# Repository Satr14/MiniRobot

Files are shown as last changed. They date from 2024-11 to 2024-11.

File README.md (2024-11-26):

Tugas Pemrogaman Sistem Mekatronik

-> MINI ROBOT <-

-> Arduino Nano Wall Follower <-

Not Use : RST,D8,D9,REF

Button
	RST : reset

Switch Komunikasi Antar Arduino
	1: RX -> TX
	2: TX -> RX

Modul wifi ESP diganti dengan modul Bluetooth
	D10 (RX/PWM) : RX
	D11 (TX/Mosi1) : TX
	3V3	: Vcc dan Ch_Pd/En
	GND	: GND dan GPIO 0
	Not Use : (reset),(GPIO 2)

IMU 6050
	3V3 : pin 1 (3v3)
	A4 : pin 4 (SDA)
	A5 : pin 3 (SCL)
	no use : sisanya 
Yang digunakan untuk heading hanya sumbu z saja

Ultrasonic Kanan 
	Trig : D7
	Echo : D6
	
Ultrasonic Kiri
	Trig : D3
	Echo : D2

Ultrasonic Depan
	Trig : D5
	Echo : D4

-> Arduino Nano Line Follower <-

Not Use : RST,REF,A7

LCD I2C
	Address: 0X27
	A4 : SDA
	A5 : SCL

Driver Motor (HW-166)
	PWMA : D3
	AIN2 : D2
	AIN1 : D4
	STBY : D9
	BIN1 : D7
	BIN2 : D8
	PWMB : D5

Buzzer 
	Transistor : D6

Button
	RST : reset
	D12(1) : D12
	D11(2) : D11
	D13(3) : D13

Led
	- : D10

Led & Infrared
	infrared 1 : A0
	infrared 2 : A1
	infrared 3 : A2
	infrared 4 : A3
	infrared 5 : A6
	
Pembacaan Putih <720
Pembacaan Hitam >880

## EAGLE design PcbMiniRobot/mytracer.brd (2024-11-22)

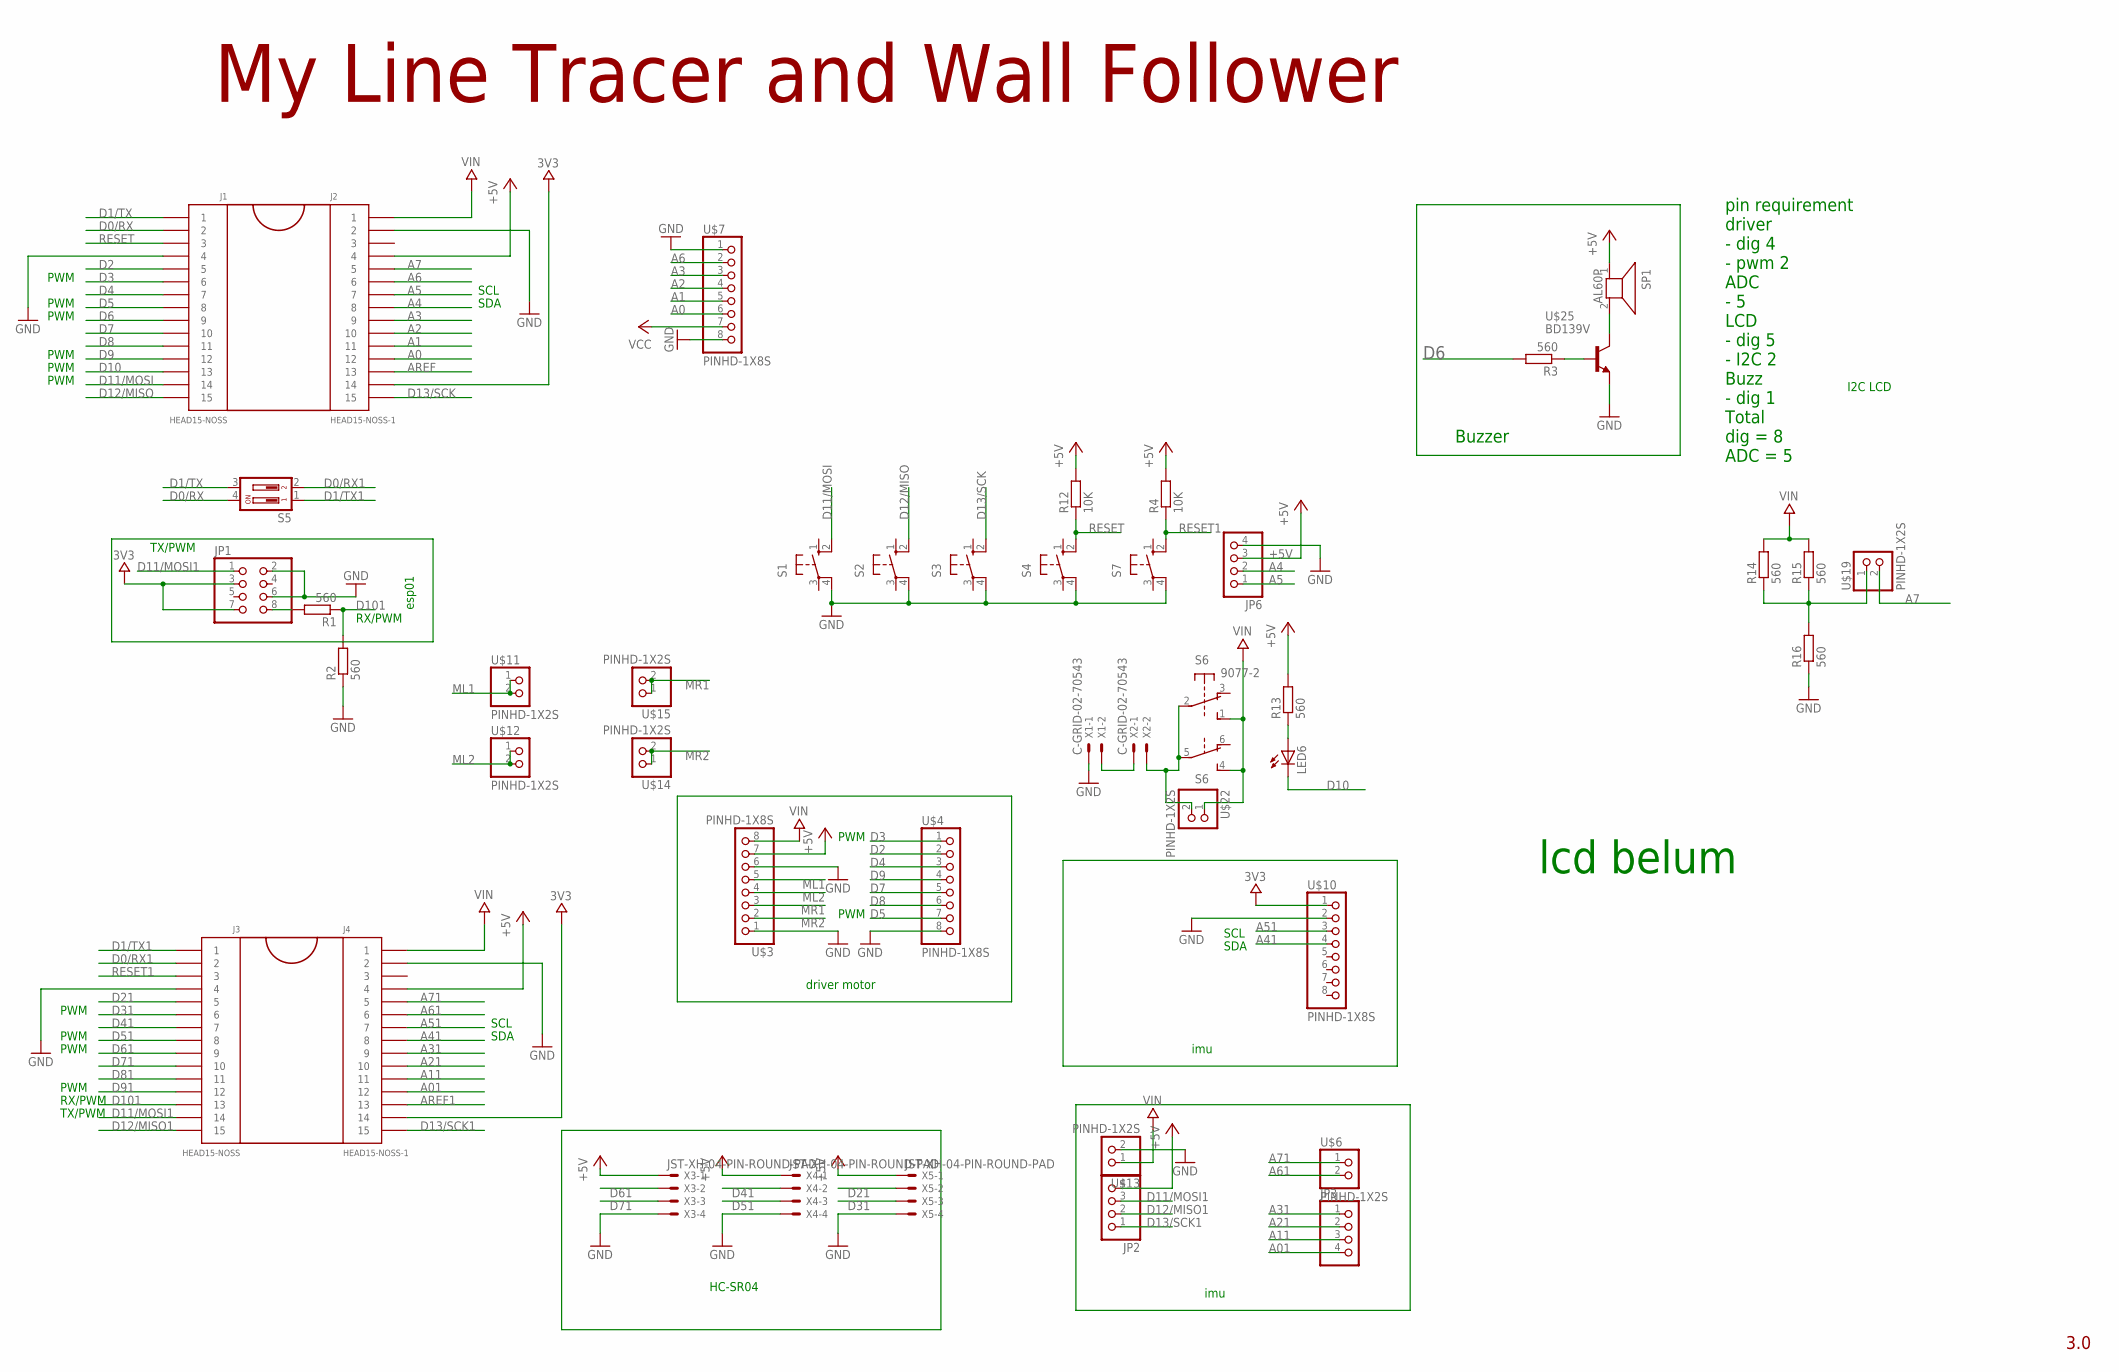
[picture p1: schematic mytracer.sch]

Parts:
J1, J3: HEAD15-NOSS
J2, J4: HEAD15-NOSS-1
JP1: PINHD-2X4; 2X04
JP2, JP3, JP6: PINHD-1X4; 1X04
LED6: LED3MM
R1, R2, R3, R13, R14, R15, R16: 560; M1206
R4, R12: 10K; M1206
S1, S2, S3, S4, S7: 10-XX; B3F-10XX
S5: DIP02YL
S6: 9077-2
SP1: AL60P
U$3, U$4, U$7, U$10: PINHD-1X8S; 1X08S
U$6, U$11, U$12, U$13, U$14, U$15, U$19, U$22: PINHD-1X2S; 1X02S
U$25: BD139V; TO126V
X1, X2: C-GRID-02-70543; 70543-02
X3, X4, X5: JST-XH-04-PIN-ROUND-PAD; JST-XH-04-PACKAGE-ROUND-PAD

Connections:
3V3: J2.14, J4.14, JP1.3, JP1.7, U$10.1
+5V: J2.4, J4.4, JP2.4, JP6.3, R4.2, R12.2, R13.2, SP1.1, U$3.7, X3.1, X4.1, X5.1
A0: J2.12, U$7.6
A1: J2.11, U$7.5
A01: J4.12, JP3.4
A2: J2.10, U$7.4
A3: J2.9, U$7.3
A4: J2.8, JP6.2
A5: J2.7, JP6.1
A6: J2.6, U$7.2
A7: J2.5, U$19.2
A11: J4.11, JP3.3
A21: J4.10, JP3.2
A31: J4.9, JP3.1
A41: J4.8, U$10.4
A51: J4.7, U$10.3
A61: J4.6, U$6.2
A71: J4.5, U$6.1
AREF: J2.13
AREF1: J4.13
D0/RX: J1.2, S5.4
D0/RX1: J3.2, S5.2
D1/TX: J1.1, S5.3
D1/TX1: J3.1, S5.1
D2: J1.5, U$4.2
D3: J1.6, U$4.1
D4: J1.7, U$4.3
D5: J1.8, U$4.7
D6: J1.9, R3.2
D7: J1.10, U$4.5
D8: J1.11, U$4.6
D9: J1.12, U$4.4
D10: J1.13, LED6.K (C)
D11/MOSI: J1.14, S1.2 (S1)
D11/MOSI1: J3.14, JP1.1, JP2.3
D12/MISO: J1.15, S2.2 (S1)
D12/MISO1: J3.15, JP2.2
D13/SCK: J2.15, S3.2 (S1)
D13/SCK1: J4.15, JP2.1
D21: J3.5, X5.2
D31: J3.6, X5.3
D41: J3.7, X4.2
D51: J3.8, X4.3
D61: J3.9, X3.2
D71: J3.10, X3.3
D81: J3.11
D91: J3.12
D101: J3.13, R1.1, R2.2
GND: J1.4, J2.2, J3.4, J4.2, JP1.2, JP1.6, JP6.4, R2.1, R16.1, S1.4 (P1), S2.4 (P1), S3.4 (P1), S4.4 (P1), S7.4 (P1), U$3.1, U$3.6, U$4.8, U$7.1, U$7.8, U$10.2, U$13.2, U$25.1 (E), X1.1, X3.4, X4.4, X5.4
ML1: U$3.5, U$11.1, U$11.2
ML2: U$3.4, U$12.1, U$12.2
MR1: U$3.3, U$15.1, U$15.2
MR2: U$3.2, U$14.1, U$14.2
unnamed: R14.1, R15.1, R16.2, U$19.1
unnamed: JP1.8, R1.2
unnamed: X1.2, X2.1
unnamed: S6.2, S6.5, U$22.2, X2.2
unnamed: LED6.A, R13.1
unnamed: R3.1, U$25.3 (B)
unnamed: SP1.2, U$25.2 (C)
RESET: J1.3, R12.1, S4.2 (S1)
RESET1: J3.3, R4.1, S7.2 (S1)
VCC: U$7.7
VIN: J2.1, J4.1, R14.2, R15.2, S6.1 (S), S6.4 (S), U$3.8, U$13.1, U$22.1

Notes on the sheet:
My Line Tracer and Wall Follower
3.0
Buzzer
pin requirement driver - dig 4 - pwm 2 ADC - 5 LCD - dig 5 - I2C 2 Buzz - dig 1 Total dig = 8 ADC = 5
SDA
SCL
PWM
I2C LCD
esp01
RX/PWM
TX/PWM
driver motor
imu
HC-SR04
lcd belum

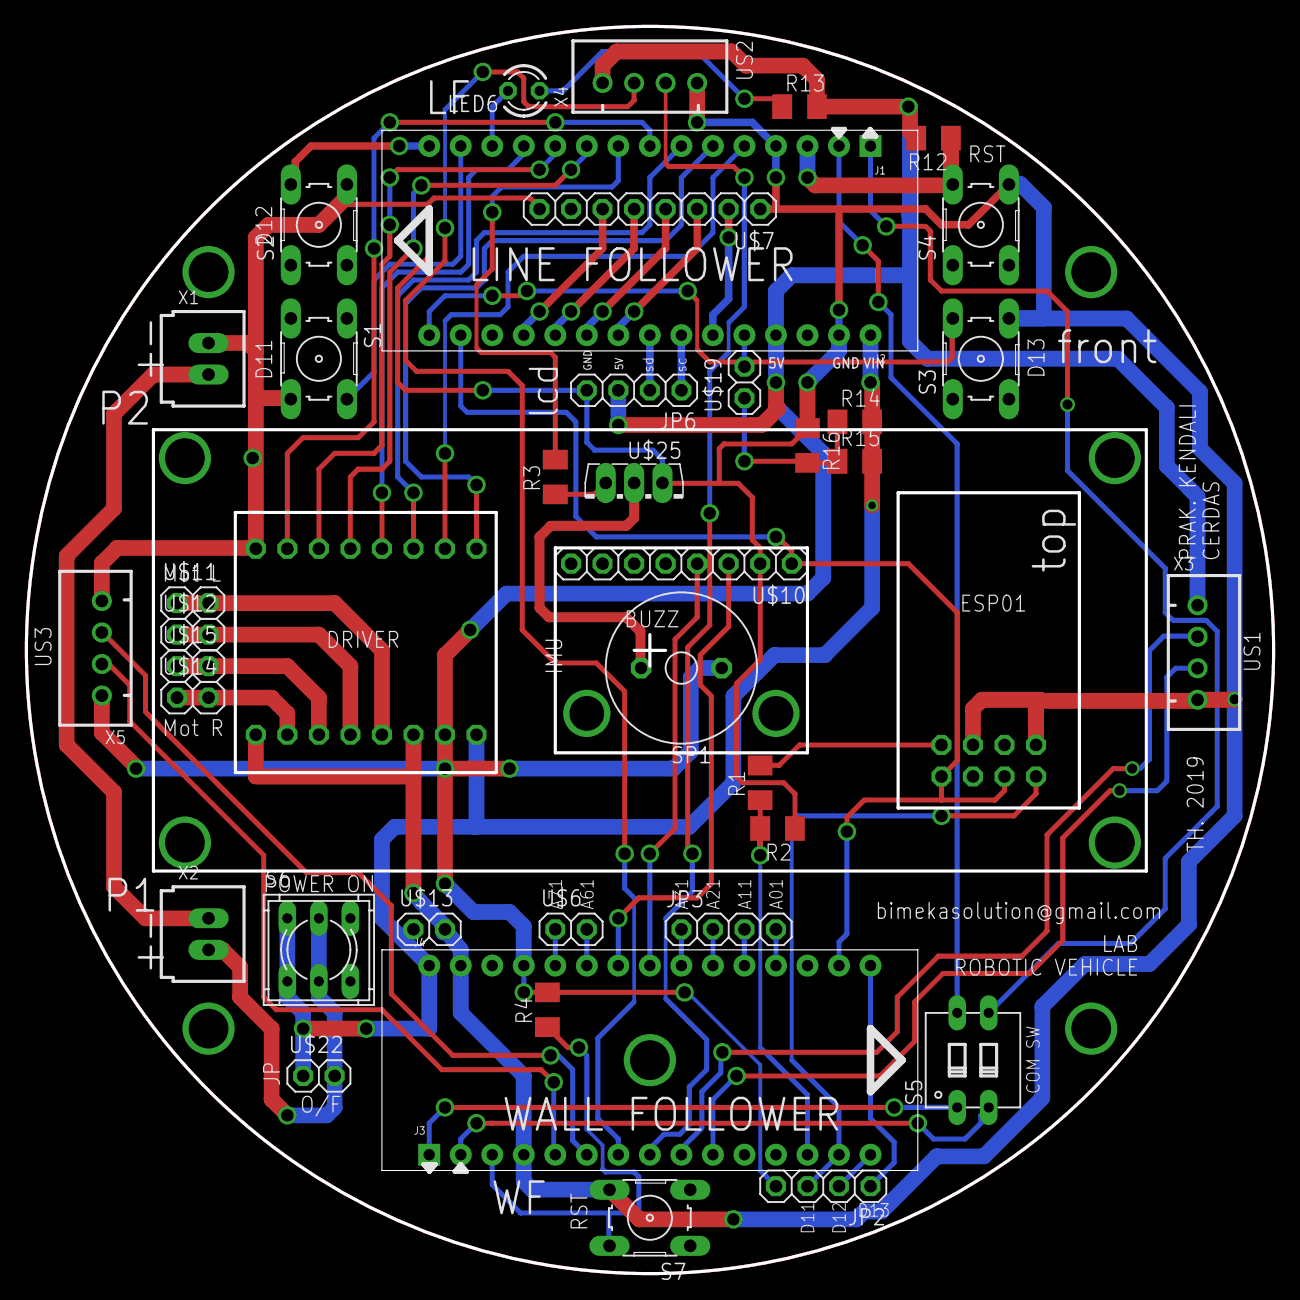
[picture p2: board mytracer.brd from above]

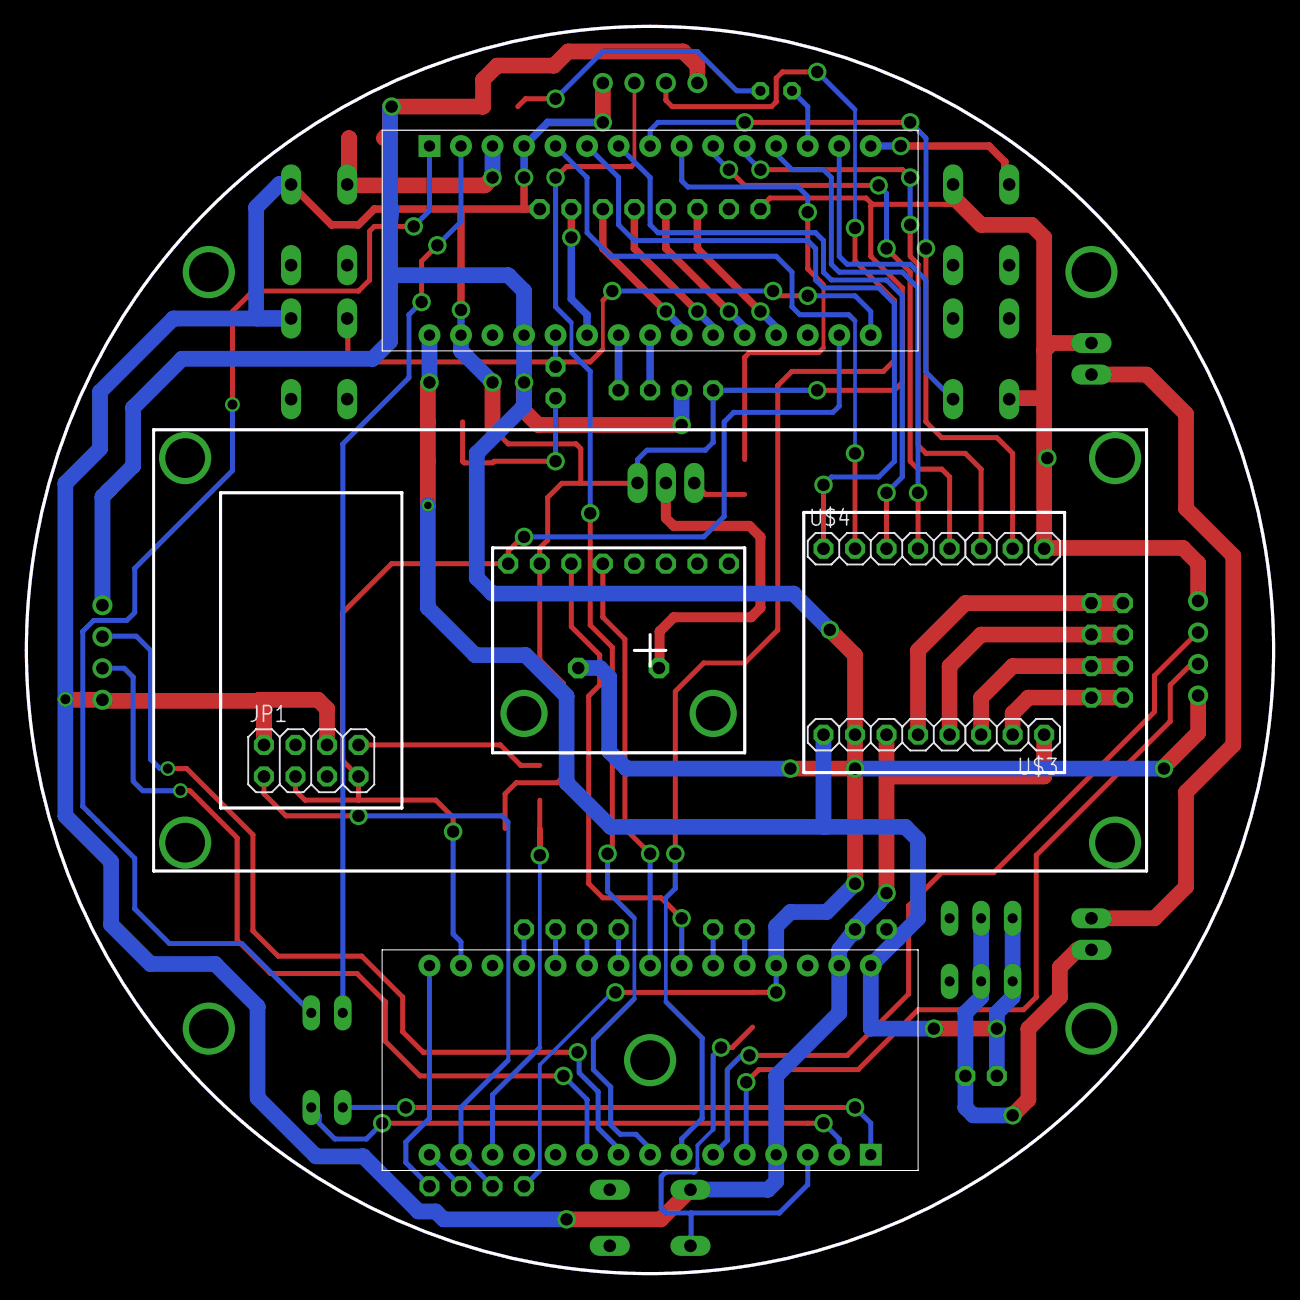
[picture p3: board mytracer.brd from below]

Board: 2 copper layers, 100.5 x 100.5 mm, 44 parts (3 on the bottom side), 59 nets.

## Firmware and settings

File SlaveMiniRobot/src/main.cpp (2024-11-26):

#include <Arduino.h>
#include <Wire.h>
#include <LiquidCrystal_I2C.h>

// Define pin motor
#define PWM1 3   // Motor A PWM
#define AIN1 2   // Motor A IN1
#define AIN2 4   // Motor A IN2
#define STBY 9   // Standby pin
#define PWM2 5   // Motor B PWM
#define BIN1 7   // Motor B IN1
#define BIN2 8   // Motor B IN2

// Define pin infrared sensors
const int IFR1 = A0;
const int IFR2 = A1;
const int IFR3 = A2;
const int IFR4 = A3;
const int IFR5 = A6;

const int led = 10;  // Pin LED for indication (optional)

// Buffer size for moving average
const int bufferSize = 10;

// Buffers for each sensor to store recent readings
int bufferIFR1[bufferSize] = {0};
int bufferIFR2[bufferSize] = {0};
int bufferIFR3[bufferSize] = {0};
int bufferIFR4[bufferSize] = {0};
int bufferIFR5[bufferSize] = {0};

// Index to keep track of the current position in the buffer
int bufferIndex = 0;

// Function to compute the moving average for a sensor
int movingAverage(int buffer[], int newValue) {
  buffer[bufferIndex] = newValue;  // Update the buffer with the new value
  int sum = 0;
  
  // Calculate the sum of all values in the buffer
  for (int i = 0; i < bufferSize; i++) {
    sum += buffer[i];
  }
  
  return sum / bufferSize;  // Return the average
}

// Set up motor
void setupMotors() {
  pinMode(PWM1, OUTPUT);  // Motor A PWM
  pinMode(AIN1, OUTPUT);  // Motor A IN1
  pinMode(AIN2, OUTPUT);  // Motor A IN2
  pinMode(STBY, OUTPUT);  // Standby pin
  pinMode(PWM2, OUTPUT);  // Motor B PWM
  pinMode(BIN1, OUTPUT);  // Motor B IN1
  pinMode(BIN2, OUTPUT);  // Motor B IN2
  
  digitalWrite(STBY, HIGH); // Ensure motors are not in standby
}

void motorB_CW(int speed) {
  digitalWrite(AIN1, HIGH); // AIN1 HIGH
  digitalWrite(AIN2, LOW);  // AIN2 LOW
  analogWrite(PWM1, speed); // Set motor speed using PWM
}

void motorB_CCW(int speed) { // Maju
  digitalWrite(AIN1, LOW);  // AIN1 LOW
  digitalWrite(AIN2, HIGH); // AIN2 HIGH
  analogWrite(PWM1, speed); // Set motor speed using PWM
}

void motorA_CW(int speed) {
  digitalWrite(BIN1, HIGH); // BIN1 HIGH
  digitalWrite(BIN2, LOW);  // BIN2 LOW
  analogWrite(PWM2, speed); // Set motor speed using PWM
}

void motorA_CCW(int speed) { // Maju
  digitalWrite(BIN1, LOW);  // BIN1 LOW
  digitalWrite(BIN2, HIGH); // BIN2 HIGH
  analogWrite(PWM2, speed); // Set motor speed using PWM
}

char Incoming_value = 0;
bool lineTracerMode = false;

LiquidCrystal_I2C lcd(0x27, 16, 2); // Set the LCD address to 0x27 for a 16 chars and 2 line display

void setup() {
  setupMotors();
  Serial.begin(9600);
  lcd.init(); // Initialize the LCD
  lcd.backlight();
  lcd.setCursor(3, 0);
  lcd.print("Mini Robot");
  lcd.setCursor(2, 1);
  lcd.print("Mode: Manual");

  // Initialize infrared sensors and LED
  pinMode(IFR1, INPUT);
  pinMode(IFR2, INPUT);
  pinMode(IFR3, INPUT);
  pinMode(IFR4, INPUT);
  pinMode(IFR5, INPUT);
  pinMode(led, OUTPUT);
}

int lastDirection = 0;  // 0: tidak ada arah, 1: kiri, 2: kanan
unsigned long lastLineDetectionTime = 0;
const unsigned long MAX_NO_LINE_DURATION = 1000; // 1 detik tanpa garis

// Fungsi untuk mencari garis
void searchForLine(int lastKnownDirection) {
  // Strategi pencarian garis
  switch(lastKnownDirection) {
    case 1:  // Terakhir belok kiri
      // Putar mencari garis ke kiri
      motorA_CCW(50);
      motorB_CW(50);
      digitalWrite(led, LOW);
      break;
    
    case 2:  // Terakhir belok kanan
      // Putar mencari garis ke kanan
      motorA_CW(50);
      motorB_CCW(50);
      digitalWrite(led, LOW);
      break;
    
    default:  // Jika tidak ada arah yang diketahui
      // Putar di tempat secara bergantian
      static bool searchDirection = true;
      if (searchDirection) {
        motorA_CCW(50);
        motorB_CW(50);
      } else {
        motorA_CW(50);
        motorB_CCW(50);
      }
      searchDirection = !searchDirection;
      digitalWrite(led, LOW);
      break;
  }
}

// Fungsi untuk melanjutkan arah terakhir
void continueLastDirection() {
  switch(lastDirection) {
    case 1:  // Terakhir belok kiri
      motorA_CCW(75);
      motorB_CCW(50);
      digitalWrite(led, LOW);
      break;
    
    case 2:  // Terakhir belok kanan
      motorA_CCW(50);
      motorB_CCW(75);
      digitalWrite(led, LOW);
      break;
    
    default:  // Jika tidak ada arah khusus
      motorA_CCW(75);
      motorB_CCW(75);
      digitalWrite(led, LOW);
      break;
  }
}

void loop() {
  if (Serial.available() > 0) {
    Incoming_value = Serial.read();
    Serial.println(Incoming_value);

    if (Incoming_value == 'A') {
      motorB_CW(150);
      motorA_CCW(150);
    } else if (Incoming_value == 'B') {
      motorB_CCW(150);
      motorA_CCW(150);
    } else if (Incoming_value == 'C') {
      motorB_CCW(150);
      motorA_CW(150);
    } else if (Incoming_value == 'D') {
      motorB_CCW(0);
      motorA_CCW(175);
    } else if (Incoming_value == 'F') {
      motorB_CCW(175);
      motorA_CCW(0);
    } else if (Incoming_value == 'G') {
      motorB_CW(150);
      motorA_CCW(150);
    } else if (Incoming_value == 'H') {
      motorB_CW(150);
      motorA_CW(150);
    } else if (Incoming_value == 'I') {
      motorB_CCW(150);
      motorA_CW(150);
    } else if (Incoming_value == 'S') {
      motorB_CW(0);
      motorA_CW(0);
    } else if (Incoming_value == 'L') {
      lineTracerMode = true;
      lcd.clear();
      lcd.print("Mode:");
      lcd.setCursor(0, 1);
      lcd.print("Line Follower");
    } else if (Incoming_value == 'M') {
      lineTracerMode = false;
      lcd.clear();
      lcd.setCursor(3, 0);
      lcd.print("Mini Robot");
      lcd.setCursor(2, 1);
      lcd.print("Mode: Manual");
    } else if (Incoming_value == 'N') {
      lineTracerMode = false;
      lcd.clear();
      lcd.print("Mode:");
      lcd.setCursor(0, 1);
      lcd.print("Obstacle Avoider");
    } else if (Incoming_value == 'W') {
      lineTracerMode = false;
      lcd.clear();
      lcd.print("Mode:");
      lcd.setCursor(0, 1);
      lcd.print("Wall Follower");
    }
  }

  int rawIFR1 = analogRead(IFR1);
  int rawIFR2 = analogRead(IFR2);
  int rawIFR3 = analogRead(IFR3);
  int rawIFR4 = analogRead(IFR4);
  int rawIFR5 = analogRead(IFR5);
    
  // Apply moving average to each sensor reading
  int avgIFR1 = movingAverage(bufferIFR1, rawIFR1);
  int avgIFR2 = movingAverage(bufferIFR2, rawIFR2);
  int avgIFR3 = movingAverage(bufferIFR3, rawIFR3);
  int avgIFR4 = movingAverage(bufferIFR4, rawIFR4);
  int avgIFR5 = movingAverage(bufferIFR5, rawIFR5);
    
  // Increment buffer index and reset when it reaches the buffer size
  bufferIndex = (bufferIndex + 1) % bufferSize;
  // Tampilkan hasil pembacaan sensor di Serial Monitor

  String dataPrefix = "X";
  String dataLine = dataPrefix + String(avgIFR1) + "?" + String(avgIFR2) + "?" + String(avgIFR3) + "?" + String(avgIFR4) + "?" + String(avgIFR5);
  Serial.println(dataLine);
  
  if (lineTracerMode) {
    bool lineDetected = false;

    // Prioritaskan sensor tengah
    if (avgIFR3 > 890) {
      // Maju lurus
      motorA_CCW(100);
      motorB_CCW(100);
      digitalWrite(led, HIGH);
      lastDirection = 0;
      lastLineDetectionTime = millis();
      lineDetected = true;
    }
    // Sensor kiri sedikit
    else if (avgIFR2 > 890) {
      // Belok kiri sedikit
      motorA_CCW(100);
      motorB_CCW(75);
      digitalWrite(led, HIGH);
      lastDirection = 1;
      lastLineDetectionTime = millis();
      lineDetected = true;
    }
    // Sensor kanan sedikit
    else if (avgIFR4 > 890) {
      // Belok kanan sedikit
      motorA_CCW(75);
      motorB_CCW(100);
      digitalWrite(led, HIGH);
      lastDirection = 2;
      lastLineDetectionTime = millis();
      lineDetected = true;
    }
    // Sensor kiri jauh
    else if (avgIFR1 > 890) {
      // Belok kiri tajam
      motorA_CCW(100);
      motorB_CCW(50);
      digitalWrite(led, HIGH);
      lastDirection = 1;
      lastLineDetectionTime = millis();
      lineDetected = true;
    }
    // Sensor kanan jauh
    else if (avgIFR5 > 890) {
      // Belok kanan tajam
      motorA_CCW(50);
      motorB_CCW(100);
      digitalWrite(led, HIGH);
      lastDirection = 2;
      lastLineDetectionTime = millis();
      lineDetected = true;
    }
    // Jika tidak ada garis terdeteksi
    else {
      // Cari jejak garis berdasarkan arah terakhir
      unsigned long currentTime = millis();
      if (currentTime - lastLineDetectionTime > MAX_NO_LINE_DURATION) {
        // Jika sudah terlalu lama tidak menemukan garis, lakukan pencarian
        searchForLine(lastDirection);
      }
      else {
        // Lanjutkan dengan arah terakhir untuk sementara waktu
        continueLastDirection();
      }
    }
  }
}


  

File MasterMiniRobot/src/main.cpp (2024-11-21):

#include <Arduino.h>
#include <SoftwareSerial.h>
#include <Ultrasonic.h>

SoftwareSerial mySerial(11, 10); // TX, RX

char Incoming_value = 0;
bool Avoider = false;
bool Wall = false;

const int trigPinF = 5;
const int echoPinF = 4;
const int trigPinR = 7;
const int echoPinR = 6;
const int trigPinL = 3;
const int echoPinL = 2;



Ultrasonic ultrasonic1(trigPinF, echoPinF); // Front
Ultrasonic ultrasonic2(trigPinR, echoPinR); // Right
Ultrasonic ultrasonic3(trigPinL, echoPinL); // Left

int irValues[5] = {0, 0, 0, 0, 0};

void setup() {
  mySerial.begin(9600);
  Serial.begin(9600);
}


void UltrasonicSensor(){
  int distanceL = ultrasonic3.read(CM); // Left
  int distanceF = ultrasonic1.read(CM); // Front
  int distanceR = ultrasonic2.read(CM); // Right

  // Print the distance values
  mySerial.print(distanceL);
  mySerial.print("|");
  mySerial.print(distanceF);
  mySerial.print("|");
  mySerial.print(distanceR);
  mySerial.print("|");

    if (Avoider) {
      if (distanceF < 15) {
        if (distanceL < 15 && distanceR < 15) {
          Serial.println('H'); // Mundur
        } else if (distanceL < 15) {
          Serial.println('C'); // Kanan Depan
        } else if (distanceR < 15) {
          Serial.println('A'); // Kiri Depan
        } else {
          Serial.println('C'); // Kanan Depan (default action if front is blocked)
        }
      } else if (distanceL < 15) {
        Serial.println('C'); // Kanan Depan if left is blocked
      } else if (distanceR < 15) {
        Serial.println('A'); // Kiri Depan if right is blocked
      } else {
        Serial.println('B'); // Maju
      }
    }

  
if (Wall) {
  const int MAX_DIS = 30;
  const int FOLLOW_DISTANCE = 20;     // Ideal following distance
  const int TURN_THRESHOLD = 10;      // Threshold for turning
 
  if (distanceL < FOLLOW_DISTANCE && distanceF > MAX_DIS) {
        Serial.println('A');
      if (distanceF <= FOLLOW_DISTANCE && distanceF > TURN_THRESHOLD) {
        Serial.println('B');
        }
    }
  if (distanceR < FOLLOW_DISTANCE && distanceF > MAX_DIS) {
        Serial.println('C');
      if (distanceF <= FOLLOW_DISTANCE && distanceF > TURN_THRESHOLD) {
        Serial.println('B');
        }
      }
  if (distanceF <= FOLLOW_DISTANCE && distanceF > TURN_THRESHOLD && distanceL > MAX_DIS && distanceR > MAX_DIS) {
      Serial.println('B');
    }else if(distanceF > MAX_DIS && distanceL > MAX_DIS && distanceR > MAX_DIS) {
      Serial.println('S'); 
    } else if (distanceF < TURN_THRESHOLD) {
      Serial.println('H');
    }
}
}

void parseIRData(String data) {
  // Periksa awalan data
  if (data.startsWith("X")) {
    int startIndex = 1; // Abaikan awalan "X"
    int valueIndex = 0;
    for (int i = startIndex; i < data.length(); i++) {
      if (data.charAt(i) == '?' || i == data.length() - 1) {
        String valueStr = data.substring(startIndex, i);
        int value = valueStr.toInt();
        
        // Abaikan nilai di luar range 0-999
        if (value >= 0 && value <= 999) {
          irValues[valueIndex] = value;
        }
        
        startIndex = i + 1;
        valueIndex++;
        
        if (valueIndex >= 5) break; // Kita hanya ingin 5 nilai
      }
    }
  }

    mySerial.print(irValues[0]);
    mySerial.print("|");
    mySerial.print(irValues[1]);
    mySerial.print("|");
    mySerial.print(irValues[2]);
    mySerial.print("|");
    mySerial.print(irValues[3]);
    mySerial.print("|");
    mySerial.print(irValues[4]);
    mySerial.println();
  } 

void Infraredsensor(){
 if (Serial.available() > 0) {
    String irData = Serial.readStringUntil('\n');
    parseIRData(irData);
  }
}

void loop() {
  static unsigned long lastUpdateTime = 0;
  unsigned long currentTime = millis();

  if (currentTime - lastUpdateTime >= 200) {
    lastUpdateTime = currentTime;

    UltrasonicSensor();
    Infraredsensor();
  }

  if (mySerial.available() > 0) {
    Incoming_value = mySerial.read();
    Serial.println(Incoming_value);

    if (Incoming_value == 'N') {
      Avoider = true; // Switch to auto mode2
      Wall = false;
    } else if (Incoming_value == 'M') {
      Avoider = false;
      Wall = false;
      Serial.println('S');  // Switch to manual mode
    } else if (Incoming_value == 'L') {
      Avoider = false;
      Wall = false;
      Serial.println('S');
    } else if (Incoming_value == 'W') {
      Wall = true;
      Avoider = false;
      Serial.println('S');
    }
  }
}
